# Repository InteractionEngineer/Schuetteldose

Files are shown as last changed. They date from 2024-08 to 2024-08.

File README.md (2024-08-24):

#### Context

This repository holds the "firmware" for a digitalized spray can and supplements [the main repo](https://github.com/InteractionEngineer/SprayAR).
See intstructions below to learn about how we build the spray can. To connect the Schütteldose (spray can) with your Unity application read its output with a baudrate of 115200. It will display its ip adress after connecting to your network successfully.

# Firmware

We are working with an Adafruit HUZZAH32 - ESP32 Feather Board. Find it's documentaion here: https://learn.adafruit.com/adafruit-huzzah32-esp32-feather/overview

## How to contribute

* Clone this repo
* Download Arduino IDE
* Open any .ino file of this repo in that Arduino IDE
* Navigate to Tools > Board […] > Board Management > select and install ESP32
* Choose Tools > Board […] > Adafruit ESP32 Feather
* Download necessary libraries
* Create your own Credentials.h with for those entries:
  * `char* WIFI_SSID = "ssid";` _Change to your network's SSID_
  * `char* WIFI_PWD = "password";` _Change to your network's password_
  * `IPAddress PARTNER_IP = IPAddress(192, 168, 1, 100);` _Change the number to the ip of your VR goggles running your Unity app_
* Start programming

## Note

The ESP32 uses a fair amount of current, so if you're getting flakey behavior make sure you are plugging your console cable into either a motherboard USB port or a powered USB hub. Don't use the 'extra' USB port on your monitor or keyboard.

# Hardware

We take a regular spray can (400ml) and print some parts where we attatch our electronics to.

## What to get

For one controller (spray can) you need theses parts:
* microcontroller ‘HUZZAH32 - ESP32 Feather Board’
  * [@Mouser](https://www.mouser.de/ProductDetail/Adafruit/3405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), Adafruit 3405
* micro USB extension cable
  * [@Mouser](https://www.mouser.de/ProductDetail/Adafruit/3258?qs=0X/VfLRQkeNhaqgEgABzjA%3D%3D), Adafruit 3258
* _optional:_ position sensor 9-DOF orientation ‘IMU Fusion Breakout - BNO085’
  * [@Mouser](https://www.mouser.de/ProductDetail/Adafruit/4754?qs=hd1VzrDQEGjjfej09NGRTw%3D%3D), Adafruit 4754
* _optional:_ touch sensor - button ‘Momentary Capacitive Touch SNSR Breakout’
  * [@Mouser](https://www.mouser.de/ProductDetail/Adafruit/1374?qs=GURawfaeGuBM%252BW52u31eLw%3D%3D), Adafruit 1374
* circular vibrating motor ‘Vibrating Mini Motor Disc’
  * [@Mouser](https://www.mouser.de/ProductDetail/Adafruit/1201?qs=GURawfaeGuD/75V/XdSvMw%3D%3D), Adafruit 1201
* motor controller ‘DRV2605L Haptic Motor Controller’
  * [@Mouser](https://www.mouser.de/ProductDetail/Adafruit/2305?qs=GURawfaeGuAbGO9ndi1lpg%3D%3D), Adafruit 2305
* battery ‘18650 3.7V 2600mAh with BMS’
 * @[Conrad](https://www.conrad.de/de/p/keeppower-1s1p-18650-2600mah-li-ion-akku-mit-bms-schutz-18650-26j-kabel-und-stecker-836099468.html) - Keeppower 1S1P18650
* choose a pressure sensor that fits your spring:
  * pressure sensor ‘Round High Force Sensitive Resistor (FSR) - 1 - 100 Newton’
    * [@Mouser](https://www.mouser.de/ProductDetail/Adafruit/5475?qs=mELouGlnn3ceocbOvsWz0A%3D%3D), Adafruit 5475
  * pressure sensor ‘Round Force Sensitive Resistor (FSR) - 0.3 - 10 Newton’
    * [@Mouser](https://www.mouser.de/ProductDetail/Adafruit/166?qs=GURawfaeGuBZazGyM1uUyQ%3D%3D), Adafruit 166
* switch with LED ‘Rugged Metal On/Off Switch with Green LED Ring, 16 mm’
  * [@Mouser](https://www.mouser.de/ProductDetail/Adafruit/482?qs=GURawfaeGuCSwD3nFtDjxw%3D%3D), Afafruit 482
* From your own stock: spray can, pressure coil spring, press-in threads (M3(OD 5mm, L 3mm) and M3(OD 4.2mm, L 4mm)), resistors, cables, connectors, 3D printing filament, solder, etc.

## What to print

You'll find all STLs [in the print-stuff folder](https://github.com/InteractionEngineer/Schuetteldose/tree/main/print-stuff).
I also provided you a [sliced file](https://github.com/InteractionEngineer/Schuetteldose/blob/main/print-stuff/Schuetteldose_v3_04-nozzel.3mf) (for the Bambulabs slicer) with support and wall thicknesses that worked for us (we utilizes different Bambulabs printers).

## How to build it

1. print all parts
2. zip-tie the battery to the flat backside of inner volume from the "Components Tray Inner"
3. heat-press in all threads and screw electrical componentes to the inner tray
4. wire everything up using [this diagram](https://github.com/InteractionEngineer/Schuetteldose/blob/main/miscellaneous/Schematic_Sch%C3%BCtteldose_2024-04-19.pdf) for reference
5. add usb-port and switch to the outer tray
6. wire in the switch
7. use super glue to attach the inner to the outer components tray

# Known issues
* The 9-DOF Sensor is not utilized yet but will be helpful when we implement a virtual representation of the spray can in Unity.
* The touch sensor recalibrates itslef after a while so it can not check for "grab duration" as intendet - it's better for detecting changes.
* The vibration motor needs a high current signal at the beginning when "starting soft". It seems to sometimes get stuck, this is taken care of in the codebase.

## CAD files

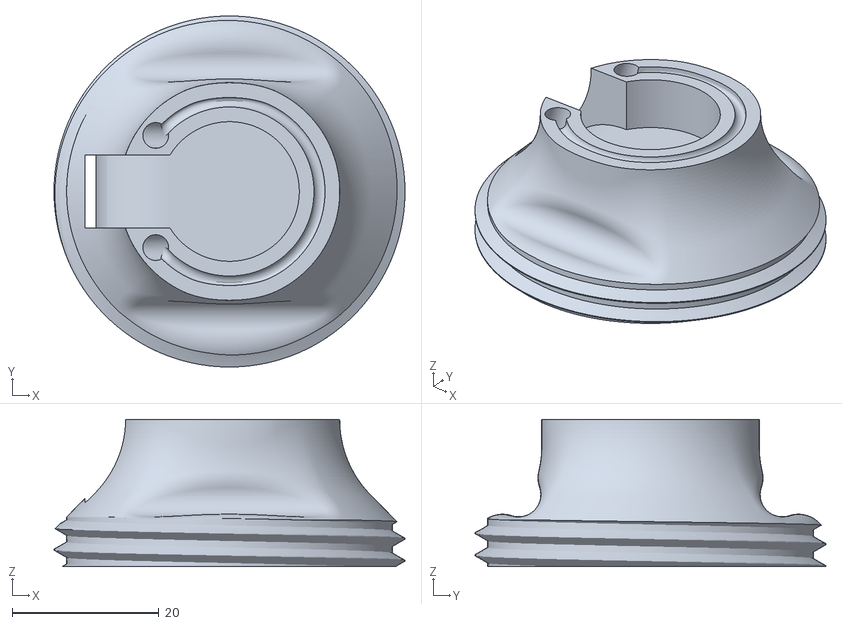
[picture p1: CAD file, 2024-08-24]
print-stuff/Top Interface.stl
47.8 x 47.8 x 20.0

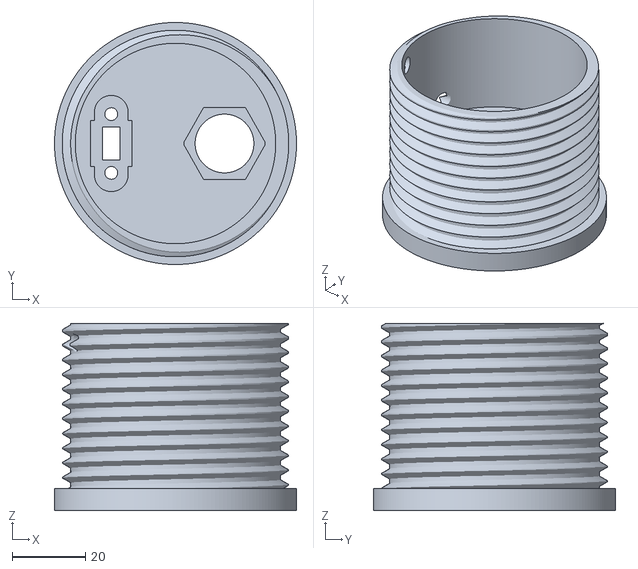
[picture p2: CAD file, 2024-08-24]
print-stuff/Compnents Tray Outer.stl
65.9 x 65.9 x 51.0

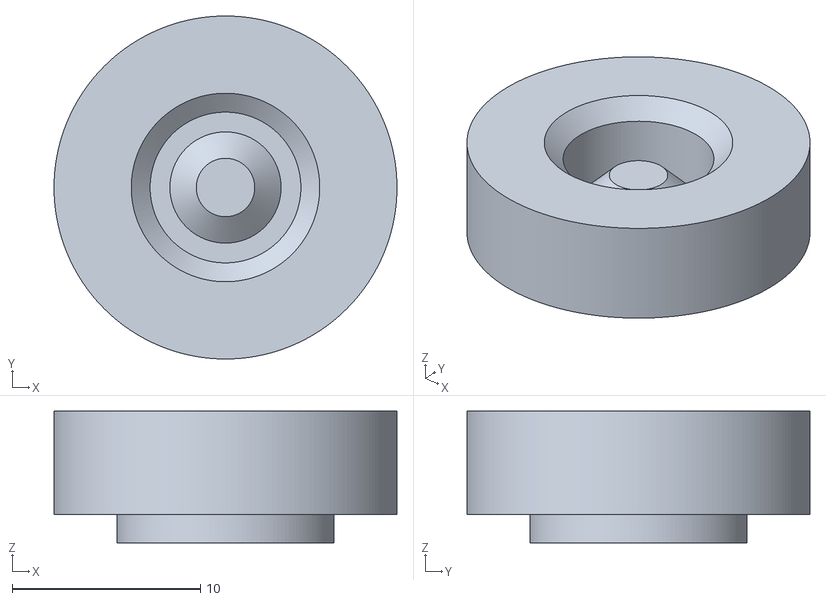
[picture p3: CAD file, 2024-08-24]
print-stuff/Spring Plate.stl
18.2 x 18.2 x 7.00

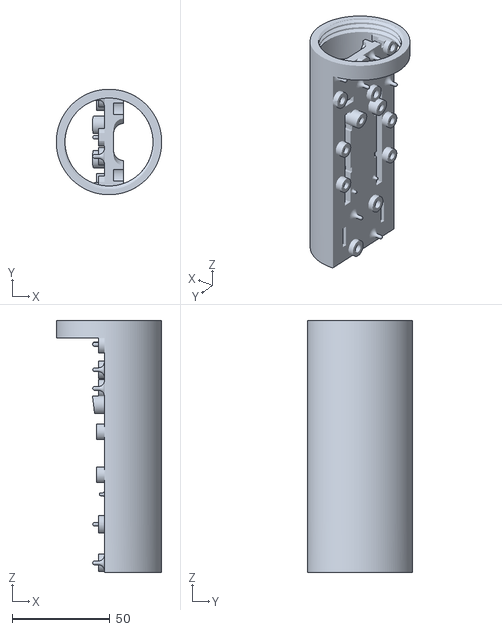
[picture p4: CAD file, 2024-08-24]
print-stuff/Compnents Tray Inner.stl
54.0 x 54.0 x 129.0

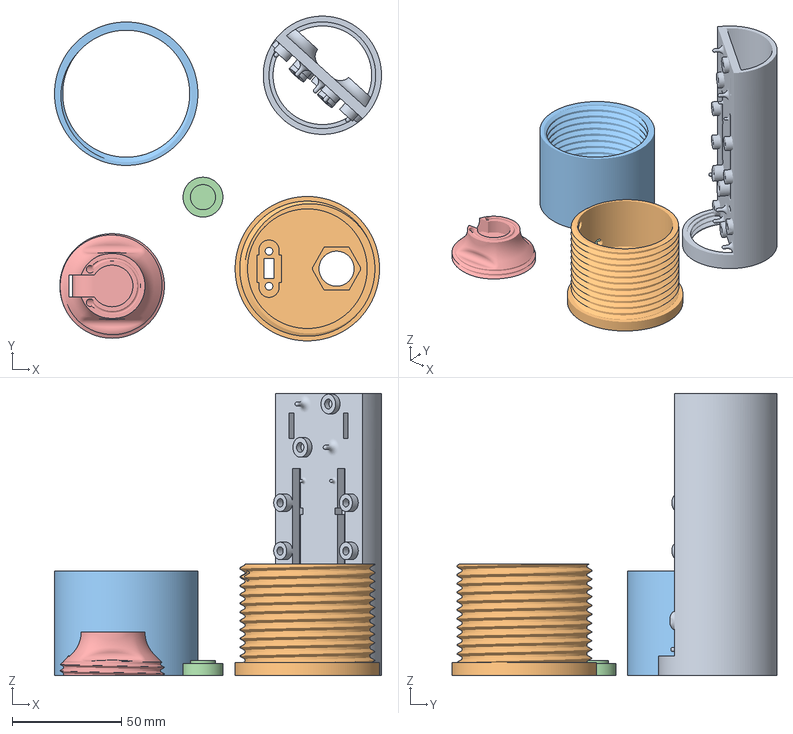
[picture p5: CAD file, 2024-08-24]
print-stuff/Schuetteldose_v3_04-nozzel.3mf
149.3 x 148.3 x 129.0 mm
Compnents Tray Inner.stl
Compnents Tray Outer.stl
Glue-In Threading.stl
Spring Plate.stl
Top Interface.stl

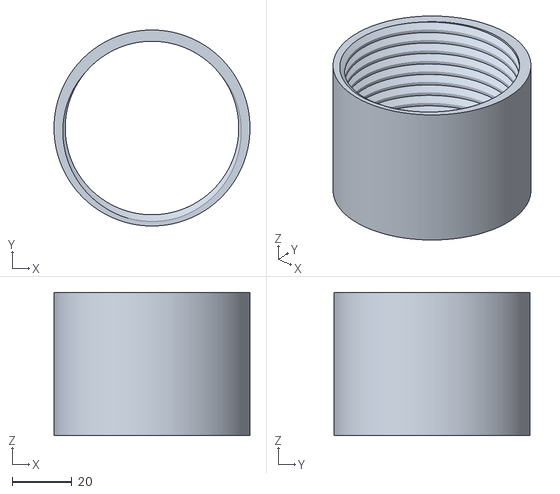
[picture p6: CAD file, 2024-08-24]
print-stuff/Glue-In Threading.stl
65.5 x 65.5 x 47.8

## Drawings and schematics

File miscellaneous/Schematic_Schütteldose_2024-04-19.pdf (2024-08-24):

## M4GND

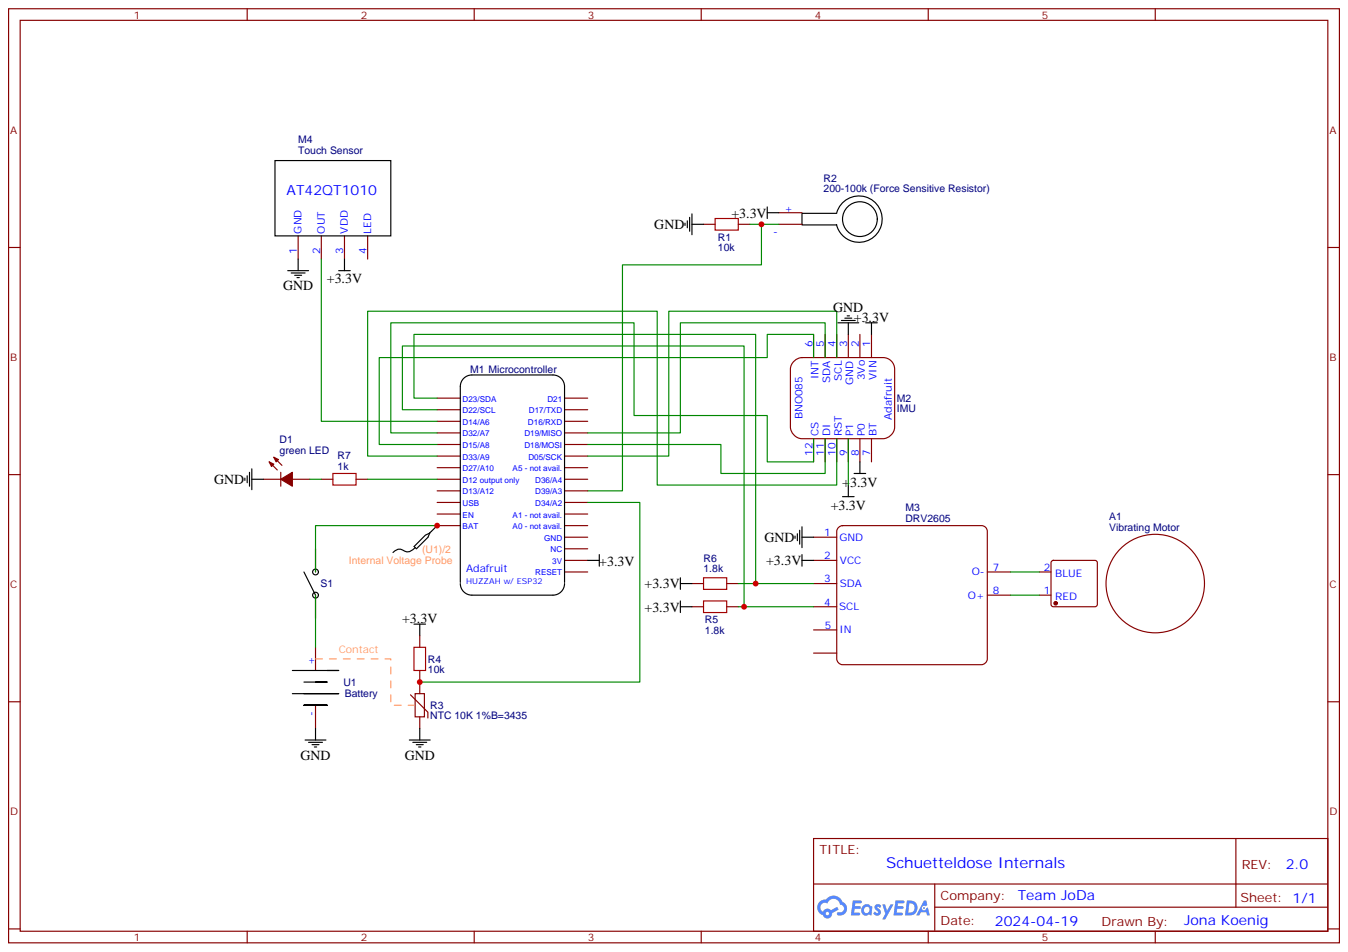
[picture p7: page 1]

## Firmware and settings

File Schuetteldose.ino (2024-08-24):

#include "LED.h"
#include "Touch.h"
#include "BMS.h"
#include "Force.h"
#include "Vibration.h"
#include "Adafruit_DRV2605.h"
#include "OSC.h"
#include "Credentials.h"

LED switchLED(12);
Touch housing(A6);
BMS batteryManagement(A13, A4, A2);
Force appliedForce(A3);
Adafruit_DRV2605 drv;
Vibration hapticFeedback(&drv);
OSC oscHandler(WIFI_SSID, WIFI_PWD, PARTNER_IP, 8888, 9999);

// controlled from outside (via OSC)
bool isFilled;
bool refilling;

// controlled by loop
long lastBatteryMillis;
long lastPingMillis;

// constants
const int INTERVAL_BATTERY = 30 * 1000;
const int INTERVAL_PING = 1 * 1000;

void setup() {
  Serial.begin(115200);

  drv.begin();
  drv.setMode(DRV2605_MODE_INTTRIG);  // internal trigger, listens for go() command
  drv.selectLibrary(1);

  isFilled = true;
  refilling = false;
  lastPingMillis = millis();
  lastBatteryMillis = millis();

  oscHandler.setup(&switchLED);
}

void loop() {
  int force = appliedForce.measure();
  bool touched = housing.isTouched();
  float voltage = batteryManagement.getVoltage();

  transmitState(force, touched);
  handleFeedback(force);
  sendPing();
  checkBattery(voltage);
  handleCharging(voltage);
  switchLED.handleState();
  oscReceiveWrapper();
}

void oscReceiveWrapper() {
  OSCMessage msg;
  oscHandler.receive(msg);
  if (!msg.hasError()) {
    msg.dispatch(
      "/sprayar/microcontroller/Refill/Start", startRefill);
    msg.dispatch(
      "/sprayar/microcontroller/Refill/Stop", stopRefill);
    msg.dispatch(
      "/sprayar/microcontroller/FillState/Full", setFull);
    msg.dispatch(
      "/sprayar/microcontroller/FillState/Empty", setEmpty);
  }
}

void startRefill(OSCMessage&) {
  refilling = true;
}
void stopRefill(OSCMessage&) {
  refilling = false;
}
void setFull(OSCMessage&) {
  isFilled = true;
}
void setEmpty(OSCMessage&) {
  isFilled = false;
}

void sendPing() {
  if (millis() - lastPingMillis > INTERVAL_PING) {
    oscHandler.ping();
    lastPingMillis = millis();
  }
}

void checkBattery(float voltage) {
  if (millis() - lastBatteryMillis > INTERVAL_BATTERY) {
    float thermistorR = batteryManagement.readThermistor();
    oscHandler.sendCharge(voltage);
    if (voltage < 3.5) switchLED.pulse(3, 1);         // low battery
    if (thermistorR > 25000) switchLED.pulse(30, 1);  // battery too hot
    lastBatteryMillis = millis();
  }
}

void handleCharging(float voltage) {
  if (batteryManagement.isCharging()) {
    if (voltage > 4.3) switchLED.pulse(1, 1);  // Error: Plugged in but no connection to battery
    else switchLED.pulse(5, 40);               // Charging
  }
}

void transmitState(int force, bool touched) {
  int mappedForce;

  if (force > 9)
    mappedForce = 3;
  else if (force > 5)
    mappedForce = 2;
  else if (force > 0)
    mappedForce = 1;
  else mappedForce = 0;

  oscHandler.sendState(touched, mappedForce);
}

void handleFeedback(int force) {
  if (force > 0 && isFilled) {
    if (force == 1) hapticFeedback.setVibration(JUMPSTART);
    else if (force == 2) hapticFeedback.setVibration(SPRAY_LIGHT);
    else if (force < 5) hapticFeedback.setVibration(SPRAY_MEDIUM);
    else if (force < 9) hapticFeedback.setVibration(SPRAY_STRONG);
    else if (force >= 9) hapticFeedback.setVibration(SPRAY_MAX);
    else Serial.println("ERROR: There is a problem measuring the appliedForce.");
  } else if (refilling) {
    hapticFeedback.setVibration(FILL);
  } else return;

  hapticFeedback.start();
}

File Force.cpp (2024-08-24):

#include "Force.h"

Force::Force(int forcePin) {
  _pin = forcePin;
  pinMode(_pin, INPUT);
}

int Force::measure() {
  float fsrVoltage_MV = analogRead(_pin);
  if (fsrVoltage_MV == 0) return 0;

  int fsrResistance = 3300 - fsrVoltage_MV;
  fsrResistance *= 10000;  // 10K resistor in voltage divider
  fsrResistance /= fsrVoltage_MV;

  int fsrConductance = 1000000;  // 1M ohm (from documentation)
  fsrConductance /= fsrResistance;
  int fsrForce;

  fsrForce = fsrConductance / 15;  // bring observed values to 0-10 range

  return fsrForce < 0 ? 0 : fsrForce;
}

void Force::print() {
  int force = measure();
  if (force > 0) {
    Serial.print("Approximated force in Newtons: ");
    Serial.println(force);
  }
}

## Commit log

2024-04-12 Defined next steps to observe Li powersource
2024-04-12 Provided an example programm to read some values from the IMU. Also defined next steps as TODOs.
2024-04-12 We got a LED now! Defined next steps to use it for system-feedback communiaction
2024-04-19 erste Ideen für die Main
2024-04-20 added button and touch sensor functionalities, needs to be tested
2024-06-15 tried to fix vibration initialization error.
    [Schuetteldose.ino]
2024-06-21 fixed osc compiler errors
    [OSC.cpp, Schuetteldose.ino]
2024-06-21 temporary solution to make force measurements work with another sensor
2024-06-21 got vibration working; improved LED to use state-machine pattern - got it working (mostly); code qulity improvements
    [LED.cpp, Schuetteldose.ino]
2024-07-01 Added LED states to communicate system status; improved header files for better use in code
2024-07-01 Finally found OK workaround for unrelaible virbation feedback
    [BMS.cpp, Force.cpp, Schuetteldose.ino]
2024-07-01 LED Feedback complete, mapped force for OSC communication
2024-07-02 more BMS checks
2024-08-24 added 3D printer files
    If you want to further manipulate the STL files contact me directly
    [Compnents Tray Inner.stl, Compnents Tray Outer.stl, Glue-In Threading.stl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]
2024-08-24 organized in a folder
    [Compnents Tray Inner.stl, Compnents Tray Outer.stl, Glue-In Threading.stl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]
2024-08-24 Added wiring diagram
